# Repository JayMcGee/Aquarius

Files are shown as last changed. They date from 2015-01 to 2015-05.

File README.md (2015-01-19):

# Aquarius

The aquarius water quality evaluation station will be a programmable autonomous terminal. It will have acces to cellular network to transmit data to CloudIA, a scientific database and data visualisation interface.

The terminal evaluates water quality by acquiring acidity level (pH), water conductivity (µS/cm), dissolved oxygen (mg/L) and temperature(℃).  

-------------------------------------------------------------------------------------------------------------------------

La station d’évaluation de la qualité de l’eau Aquarius sera une borne autonome programmable. Elle aura la capacité de communiquer par réseau cellulaire ses données au logiciel CloudIA, une interface de visualisation de données scientifiques .

La borne permettra d’évaluer la qualité de l’eau en recueillant des mesures d’acidité (pH), de conductivité (µS/cm), de la concentration d’oxygène dissous (mg/L) et de la température (℃).

-------------------------------------------------------------------------------------------------------------------------

Aquarius is a Beaglebone Black with pH, dissolved oxygen, and conductivity sensors built by Atlas Scientific and a water temperature sensor by Dallas Semiconductor.

Each sensor has its own driver to calibrate or read a value. Those drivers are executed by an interface hosted on the apache server (/var/www) with a real-time interface written in Html connected to the server with Node.Js.

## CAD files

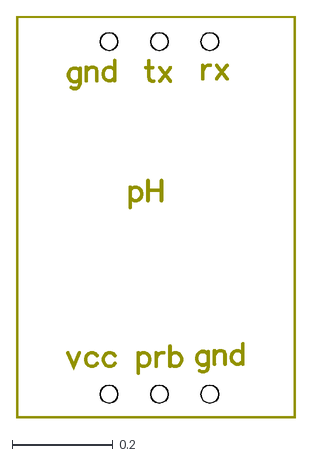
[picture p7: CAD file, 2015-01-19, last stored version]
brd/ph-layout.dxf
0.555 x 0.798

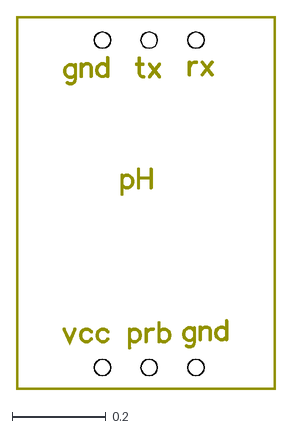
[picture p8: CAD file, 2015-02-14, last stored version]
brd_Jay_Alim/ph-layout.dxf
0.555 x 0.798

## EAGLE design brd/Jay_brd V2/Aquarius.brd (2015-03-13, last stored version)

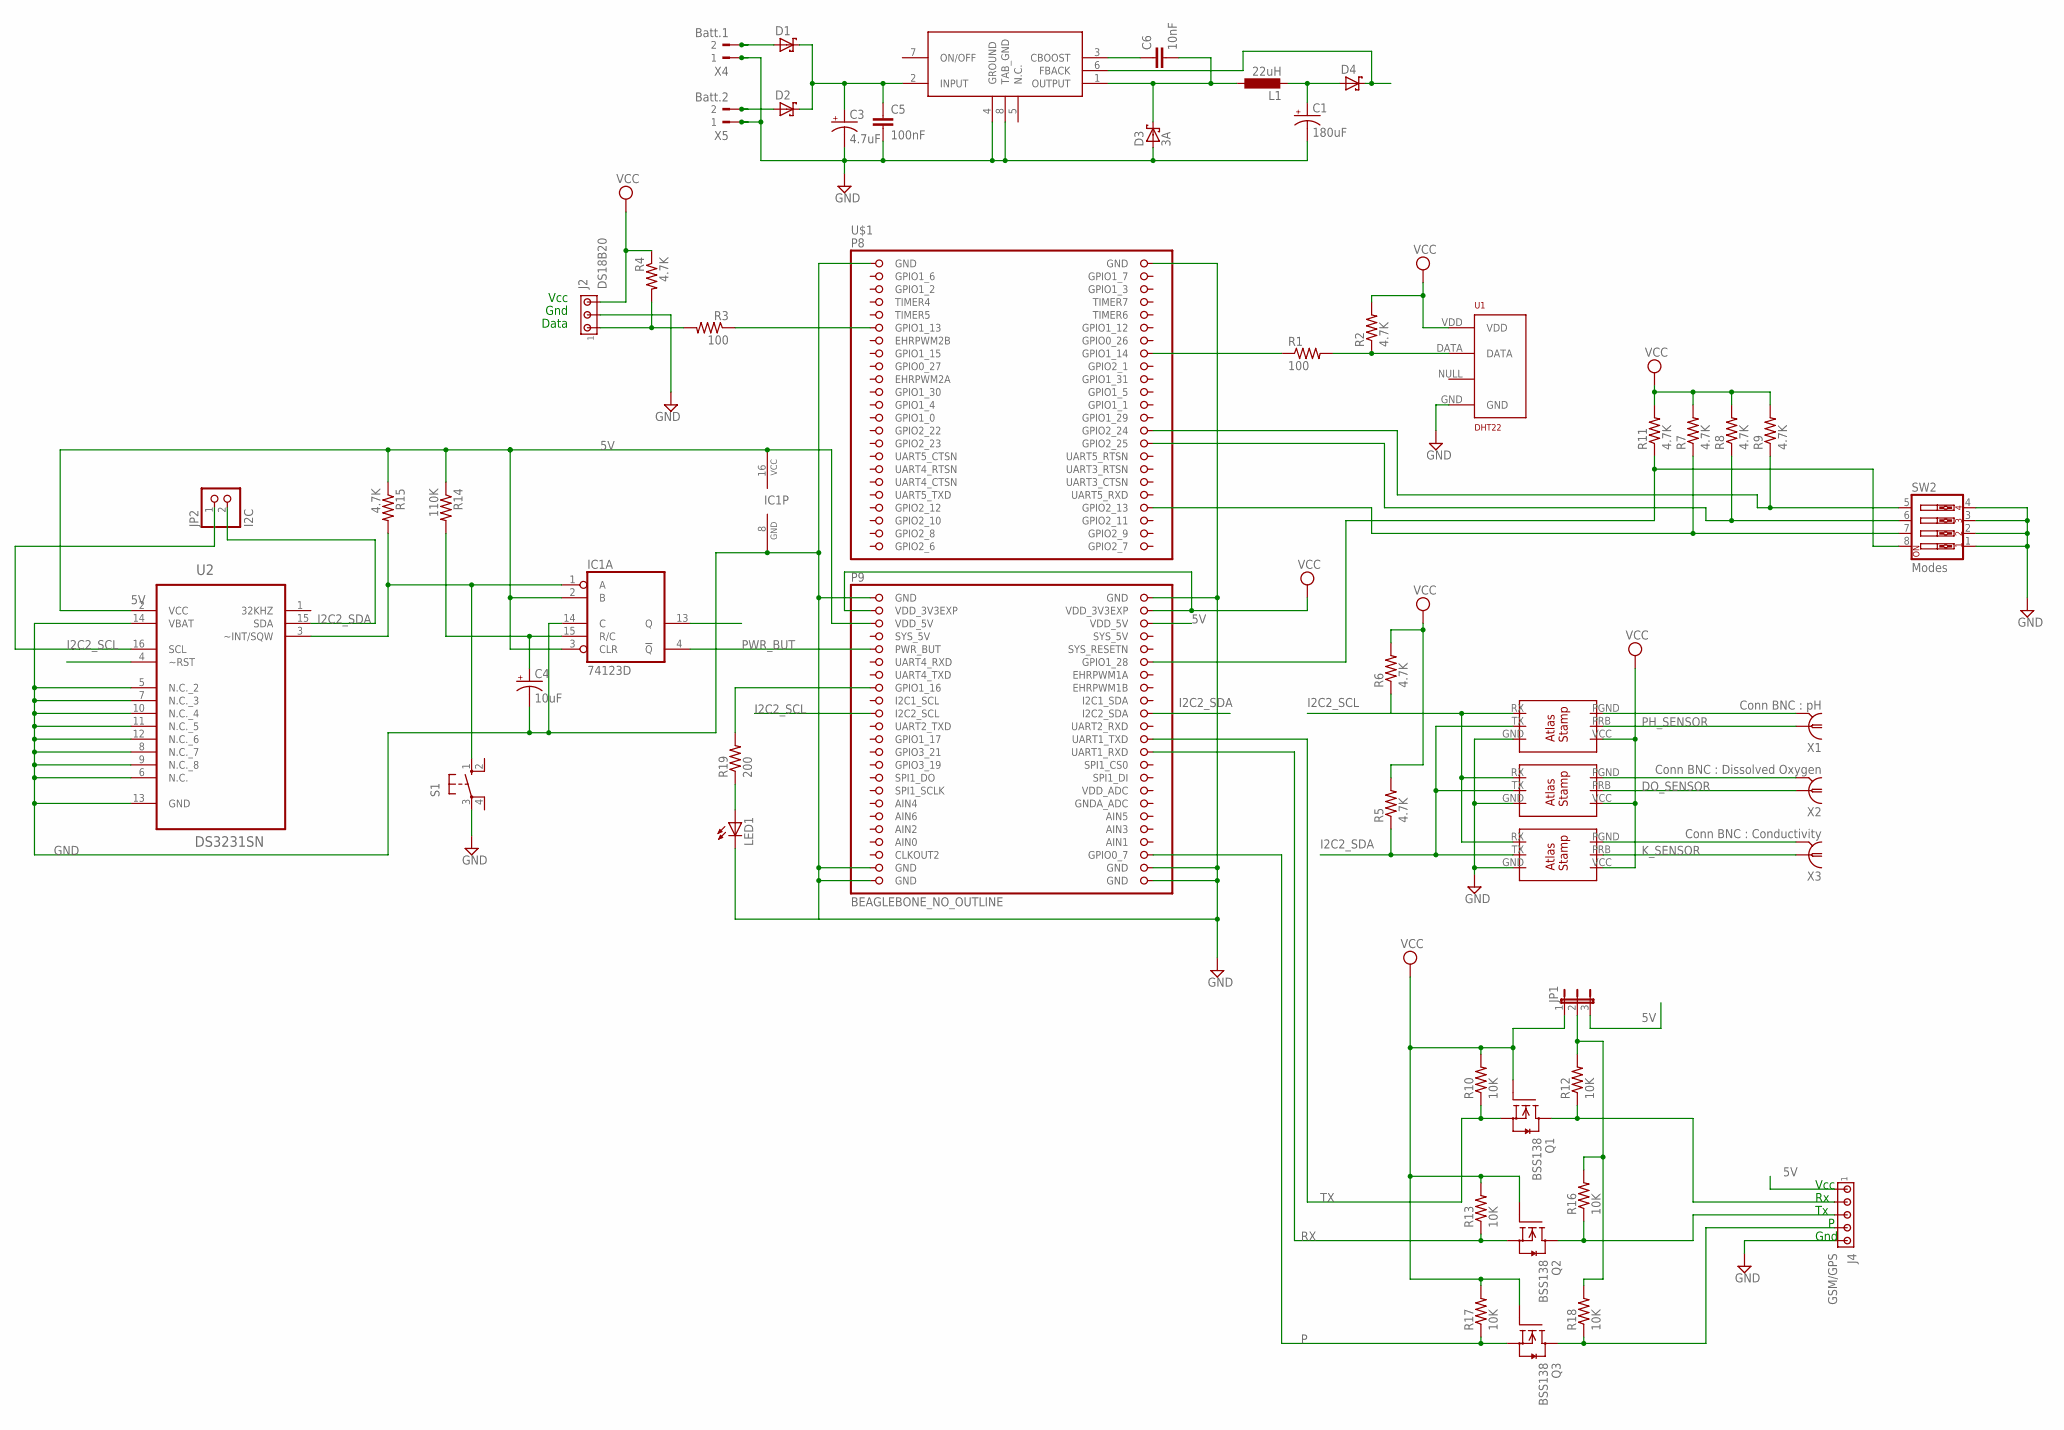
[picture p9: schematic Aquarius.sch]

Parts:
C1: 180uF; PANASONIC_D
C3: 4.7uF; PANASONIC_B
C4: 10uF; PANASONIC_B
C5: 100nF; C0805
C6: 10nF; C0805
D1, D2, D4: SCHOTTKY-DIODEDO201T15; DO201T15
D3: 3A; DO201T15
IC1: 74123D; SO16
J2: DS18B20; 10X03MTA
J4: GSM/GPS; 10X05MTA
JP1: JP2E; JP2
JP2: I2C; 1X02
L1: 22uH; EPCOS-10X10
LED1: LEDCHIP-LED0805; CHIP-LED0805
LM2678: LM2678KTW0007B; TO-PMOD7
Q1, Q2, Q3: BSS138; SOT23
R1, R3: 100; R0805
R2, R4, R5, R6, R7, R8, R9, R11, R15: 4.7K; R0805
R10, R12, R13, R16, R17, R18: 10K; R0805
R14: 110K; R0805
R19: 200; R0805
S1: 10-XX; B3F-10XX
SW2: Modes; EDG-04
U1: DHT22; AM2302
U2: DS3231SN; SOIC127P1032X265-16N
U$1: BEAGLEBONE_NO_OUTLINE; BEAGLEBONE_SHIELD_NO_OUTLINE
U$2, U$3, U$4: ATLAS_STAMP
X1: Conn BNC : pH; AMP_227161
X2: Conn BNC : Dissolved Oxygen; AMP_227161
X3: Conn BNC : Conductivity; AMP_227161
X4: Batt.1; 180G-2
X5: Batt.2; 180G-2

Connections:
5V: D4.C, IC1.2 (B), IC1.3 (CLR), IC1.16 (VCC), J4.1, JP1.3, LM2678.6 (FBACK), R14.1, R15.1, U2.2 (VCC), U$1.51 (VDD_5V), U$1.52 (VDD_5V)
AIN0: U$1.85 (AIN0)
DO_SENSOR: U$3.PRB, X2.1
GND: C1.-, C3.-, C4.-, C5.2, D3.A, IC1.8 (GND), IC1.14 (C), J2.2, J4.5, LED1.C, LM2678.4 (GROUND), LM2678.8 (TAB_GND), S1.3, SW2.1, SW2.2, SW2.3, SW2.4, U1.GND, U2.5 (N.C._2), U2.6 (N.C.), U2.7 (N.C._3), U2.8 (N.C._7), U2.9 (N.C._8), U2.10 (N.C._4), U2.11 (N.C._5), U2.12 (N.C._6), U2.13 (GND), U2.14 (VBAT), U$1.1 (GND), U$1.2 (GND), U$1.47 (GND), U$1.48 (GND), U$1.89 (GND), U$1.90 (GND), U$1.91 (GND), U$1.92 (GND), U$2.GND, U$3.GND, U$4.GND, X4.1, X5.1
I2C2_SCL: JP2.1, R6.1, U2.16 (SCL), U$1.65 (I2C2_SCL), U$2.RX, U$3.RX, U$4.RX
I2C2_SDA: JP2.2, R5.1, U2.15 (SDA), U$2.TX, U$3.TX, U$4.TX
INT: IC1.1 (A), R15.2, S1.1 (S), U2.3 (~INT/SQW)
K_SENSOR: U$4.PRB, X3.1
unnamed: J4.4, Q3.3 (D), R18.1
unnamed: D1.A, X4.2
unnamed: R1.2, R2.1, U1.DATA
unnamed: R3.1, U$1.11 (GPIO1_13)
unnamed: J2.1, R3.2, R4.2
unnamed: R1.1, U$1.16 (GPIO1_14)
unnamed: R7.1, SW2.7, U$1.40 (GPIO2_13)
unnamed: D2.A, X5.2
unnamed: C6.1, LM2678.3 (CBOOST)
unnamed: C3.+, C5.1, D1.C, D2.C, LM2678.2 (INPUT)
unnamed: U$2.PGND, X1.2
unnamed: C6.2, D3.C, L1.P$1 (1), LM2678.1 (OUTPUT)
unnamed: U$4.PGND, X3.2
unnamed: U$3.PGND, X2.2
unnamed: C1.+, D4.A, L1.P$2 (2)
unnamed: C4.+, IC1.15 (R/C), R14.2
unnamed: R11.1, SW2.8, U$1.58 (GPIO1_28)
unnamed: R8.1, SW2.6, U$1.30 (GPIO2_25)
unnamed: R9.1, SW2.5, U$1.28 (GPIO2_24)
unnamed: J4.3, Q2.3 (D), R16.1
unnamed: J4.2, Q1.3 (D), R12.1
unnamed: JP1.2, R12.2, R16.2, R18.2
unnamed: LED1.A, R19.1
unnamed: R19.2, U$1.61 (GPIO1_16)
P: Q3.2 (S), R17.1, U$1.88 (GPIO0_7)
PH_SENSOR: U$2.PRB, X1.1
PWR_BUT: IC1.4 (!Q), U$1.55 (PWR_BUT)
RX: Q2.2 (S), R13.1, U$1.72 (UART1_RXD)
SYS_5V: U$1.53 (SYS_5V)
TX: Q1.2 (S), R10.1, U$1.70 (UART1_TXD)
VCC: J2.3, JP1.1, Q1.1 (G), Q2.1 (G), Q3.1 (G), R2.2, R4.1, R5.2, R6.2, R7.2, R8.2, R9.2, R10.2, R11.2, R13.2, R17.2, U1.VDD, U$1.49 (VDD_3V3EXP), U$1.50 (VDD_3V3EXP), U$2.VCC, U$3.VCC, U$4.VCC

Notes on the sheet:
Vcc
Gnd
Data

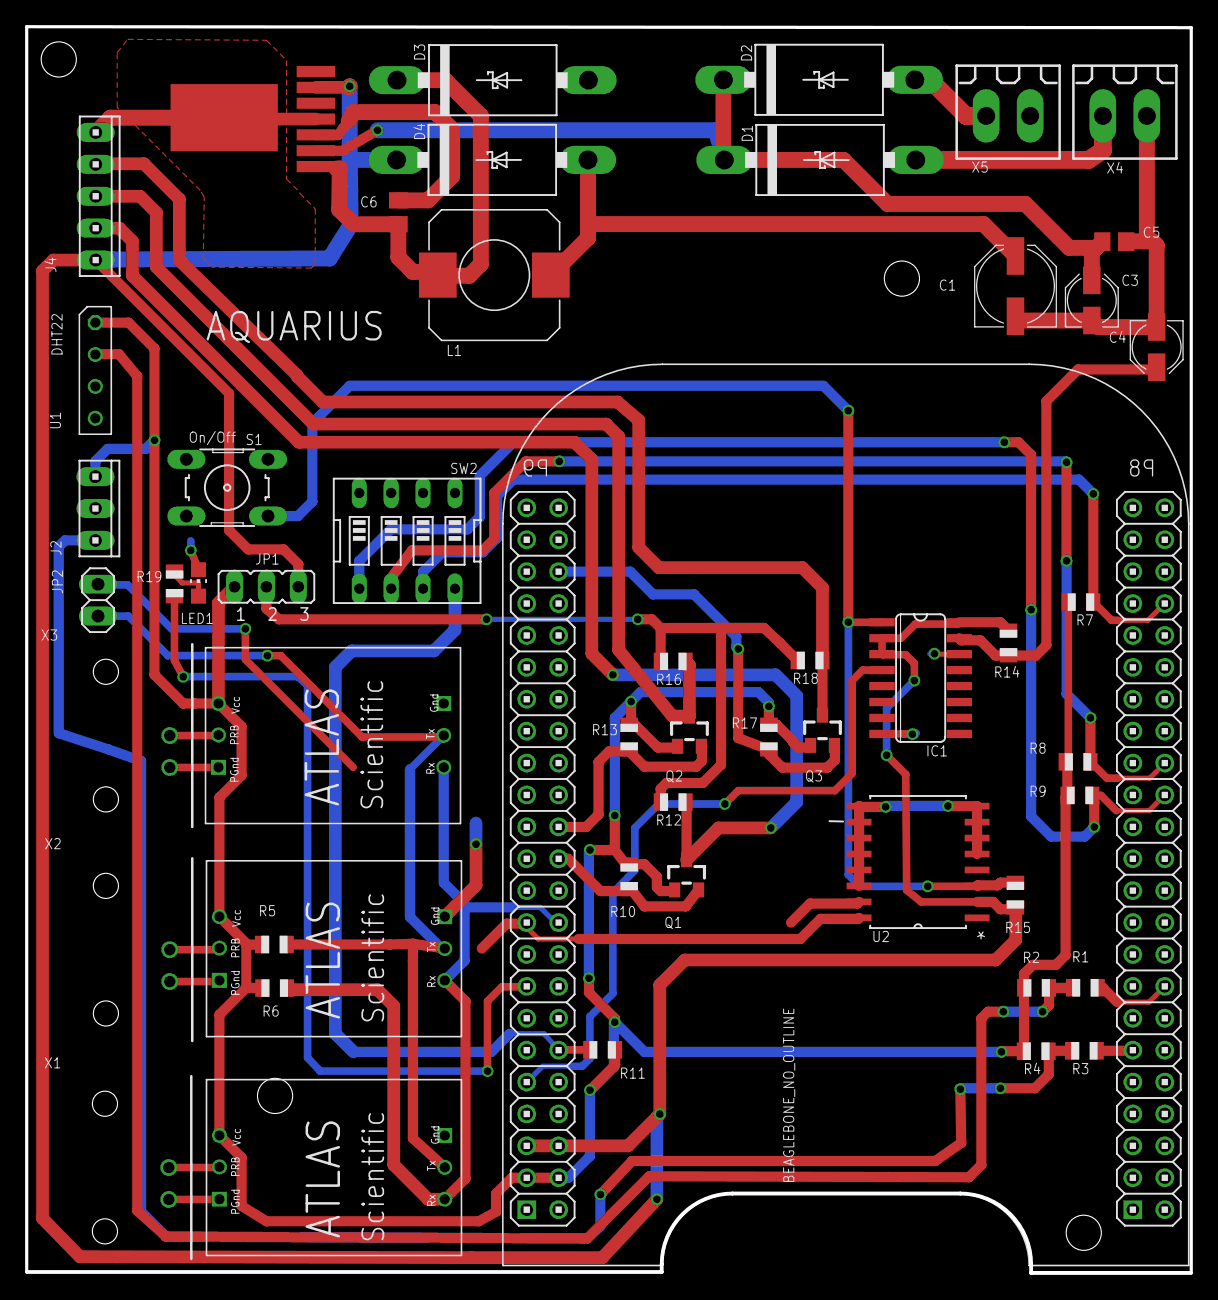
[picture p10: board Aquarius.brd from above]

Board: 2 copper layers, 92.7 x 99.2 mm, 53 parts (1 on the bottom side), 37 nets.

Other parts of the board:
DRILEGEND: DRILEGEND

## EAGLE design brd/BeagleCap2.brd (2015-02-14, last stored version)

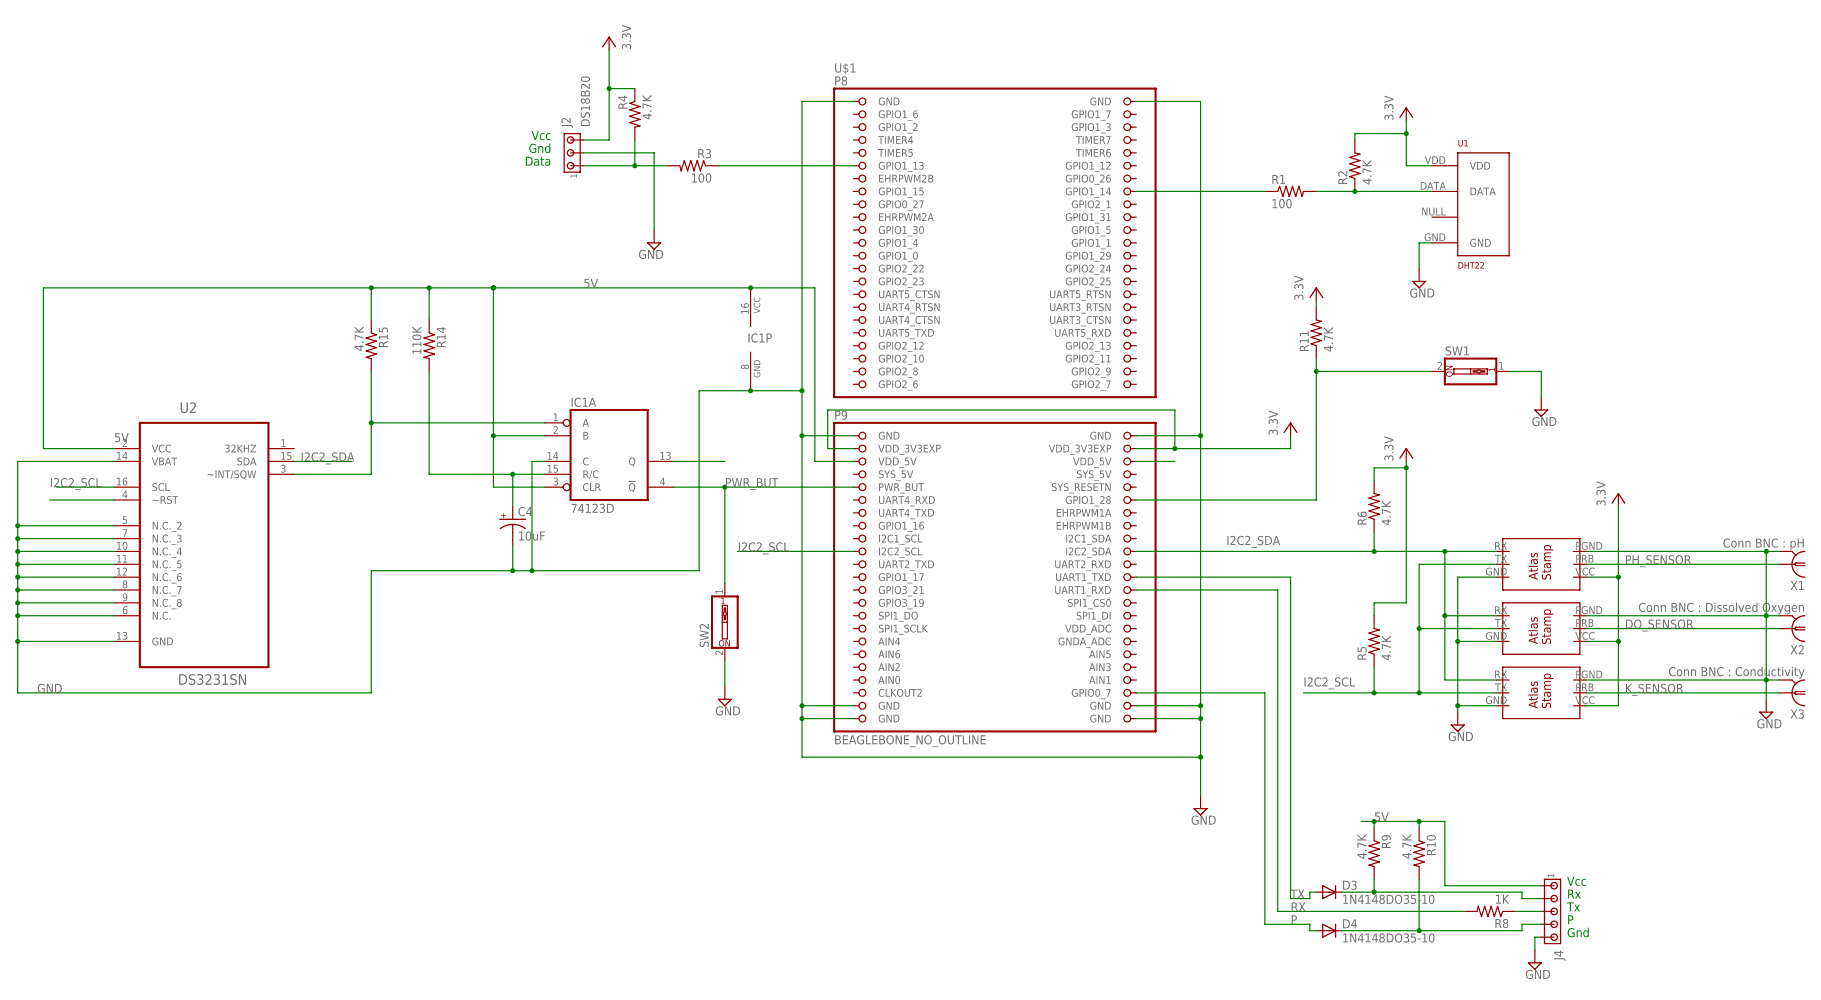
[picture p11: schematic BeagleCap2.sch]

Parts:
C4: 10uF; E2-5
D3, D4: 1N4148DO35-10; DO35-10
IC1: 74123D; SO16
J2: DS18B20; 10X03MTA
J4: MTA05-100; 10X05MTA
R1, R3: 100; R0805
R2, R4, R5, R6, R9, R10, R11, R15: 4.7K; R0805
R8: 1K; R0805
R14: 110K; R0805
SW1, SW2: SW_DIP-1; EDG-01
U1: DHT22; AM2302
U2: DS3231SN; SOIC127P1032X265-16N
U$1: BEAGLEBONE_NO_OUTLINE; BEAGLEBONE_SHIELD_NO_OUTLINE
U$2, U$3, U$4: ATLAS_STAMP
X1: Conn BNC : pH; AMP_227161
X2: Conn BNC : Dissolved Oxygen; AMP_227161
X3: Conn BNC : Conductivity; AMP_227161

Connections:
3.3V: J2.3, R2.2, R4.1, R5.2, R6.2, U1.VDD, U$1.49 (VDD_3V3EXP), U$1.50 (VDD_3V3EXP), U$2.VCC, U$3.VCC, U$4.VCC
5V: IC1.2 (B), IC1.3 (CLR), IC1.16 (VCC), J4.1, R9.1, R10.1, R14.1, R15.1, U2.2 (VCC), U$1.51 (VDD_5V)
AIN0: U$1.85 (AIN0)
DO_SENSOR: U$3.PRB, X2.1
GND: C4.-, IC1.8 (GND), IC1.14 (C), J2.2, J4.5, SW1.1, SW2.2, U1.GND, U2.5 (N.C._2), U2.6 (N.C.), U2.7 (N.C._3), U2.8 (N.C._7), U2.9 (N.C._8), U2.10 (N.C._4), U2.11 (N.C._5), U2.12 (N.C._6), U2.13 (GND), U2.14 (VBAT), U$1.1 (GND), U$1.2 (GND), U$1.47 (GND), U$1.48 (GND), U$1.89 (GND), U$1.90 (GND), U$1.91 (GND), U$1.92 (GND), U$2.GND, U$2.PGND, U$3.GND, U$3.PGND, U$4.GND, U$4.PGND, X1.2, X2.2, X3.2
I2C2_SCL: R5.1, U2.16 (SCL), U$1.65 (I2C2_SCL), U$2.TX, U$3.TX, U$4.TX
I2C2_SDA: R6.1, U2.15 (SDA), U$1.66 (I2C2_SDA), U$2.RX, U$3.RX, U$4.RX
INT: IC1.1 (A), R15.2, U2.3 (~INT/SQW)
K_SENSOR: U$4.PRB, X3.1
unnamed: R1.2, R2.1, U1.DATA
unnamed: R3.1, U$1.11 (GPIO1_13)
unnamed: J2.1, R3.2, R4.2
unnamed: R1.1, U$1.16 (GPIO1_14)
unnamed: R11.1, SW1.2, U$1.58 (GPIO1_28)
unnamed: D3.C, J4.2, R9.2
unnamed: J4.3, R8.1
unnamed: D4.C, J4.4, R10.2
unnamed: C4.+, IC1.15 (R/C), R14.2
P: D4.A, U$1.88 (GPIO0_7)
PH_SENSOR: U$2.PRB, X1.1
PWR_BUT: IC1.4 (!Q), SW2.1, U$1.55 (PWR_BUT)
RX: R8.2, U$1.72 (UART1_RXD)
SYS_5V: U$1.53 (SYS_5V)
TX: D3.A, U$1.70 (UART1_TXD)
VCC: R11.2

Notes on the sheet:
Vcc
Gnd
Data

Board: 2 copper layers, 29 parts (1 on the bottom side), 22 nets, no tracks yet.

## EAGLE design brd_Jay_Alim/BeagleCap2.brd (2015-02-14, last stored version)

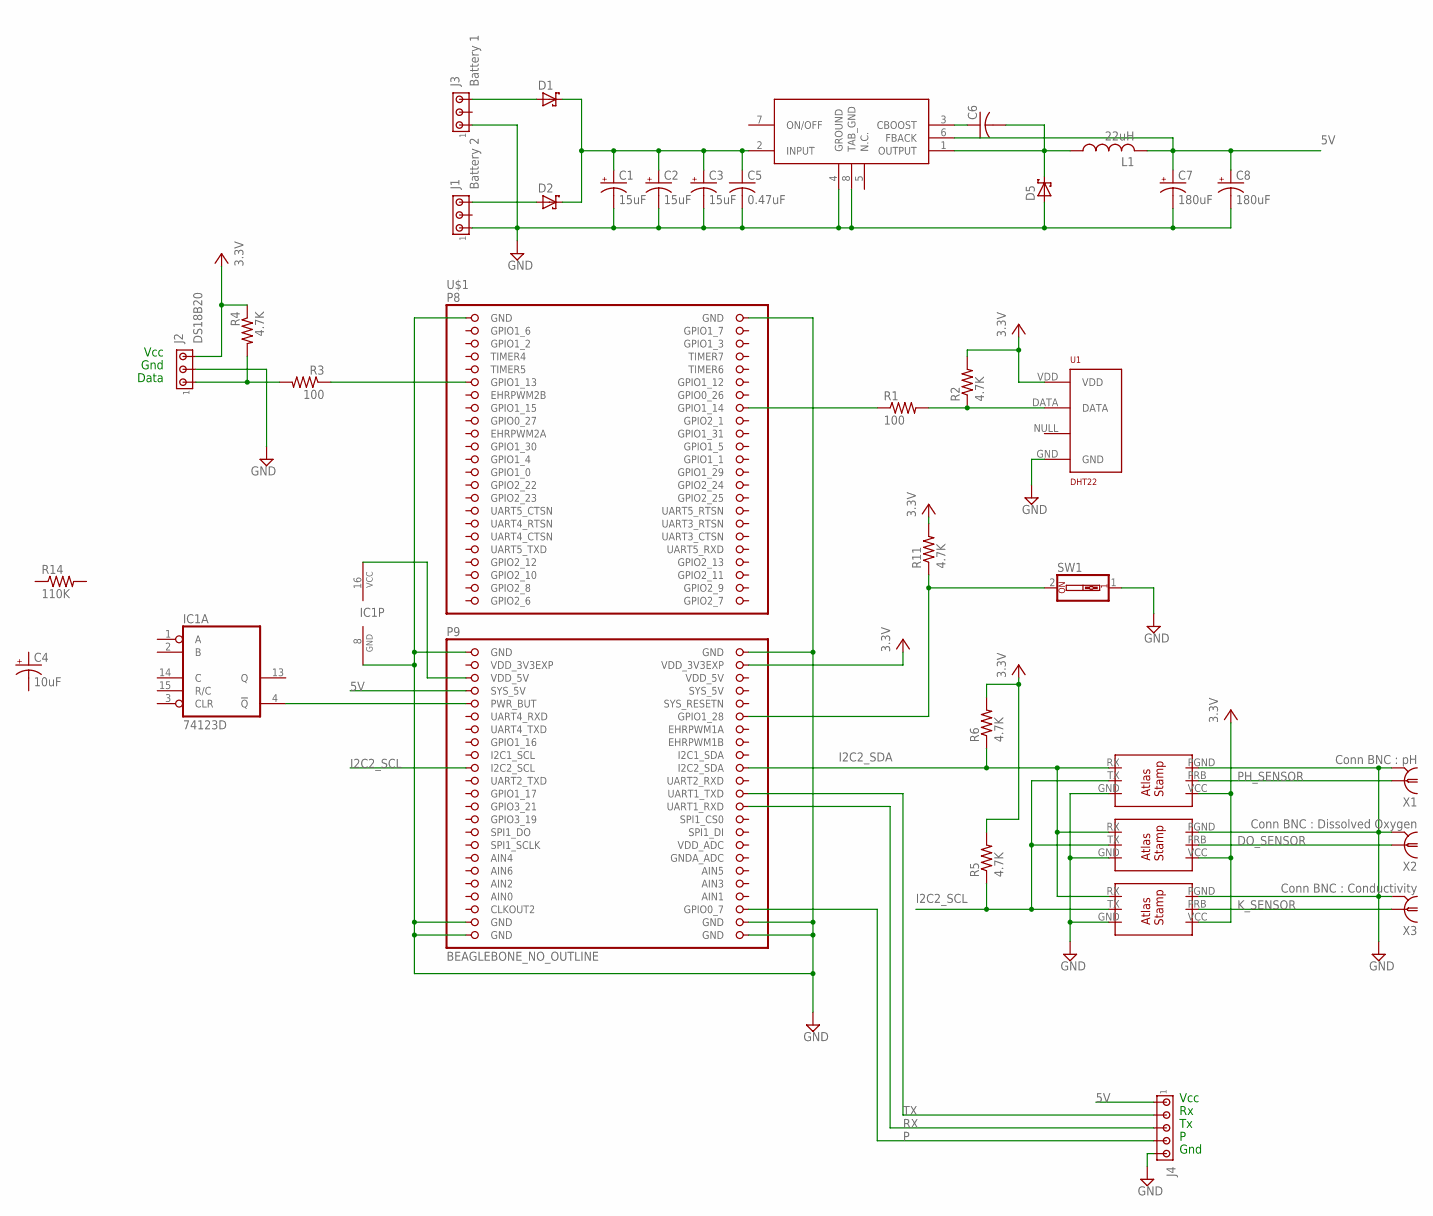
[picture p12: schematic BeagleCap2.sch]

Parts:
C1, C2, C3: 15uF; 153CLV-0405
C4: 10uF; E2-5
C5: 0.47uF; C025-025X050
C6: C-US025-025X050; C025-025X050
C7, C8: 180uF; E2,5-7
D1, D2: SCHOTTKY-DIODECB417-15; CB417-15
D5: SCHOTTKY-DIODEDO41-7; DO41-7
IC1: 74123D; SO16
J1: Battery 2; 10X03MTA
J2: DS18B20; 10X03MTA
J3: Battery 1; 10X03MTA
J4: MTA05-100; 10X05MTA
L1: 22uH; 0204/7
R1, R3: 100; R0805
R2, R4, R5, R6, R11: 4.7K; R0805
R14: 110K; R0805
SW1: SW_DIP-1; EDG-01
U1: DHT22; AM2302
U$1: BEAGLEBONE_NO_OUTLINE; BEAGLEBONE_SHIELD_NO_OUTLINE
U$2, U$3, U$4: ATLAS_STAMP
U$7: LM2678KTW0007B; TO-PMOD7
X1: Conn BNC : pH; AMP_227161
X2: Conn BNC : Dissolved Oxygen; AMP_227161
X3: Conn BNC : Conductivity; AMP_227161

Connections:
3.3V: J2.3, R2.2, R4.1, R5.2, R6.2, U1.VDD, U$1.50 (VDD_3V3EXP), U$2.VCC, U$3.VCC, U$4.VCC
5V: C7.+, C8.+, IC1.16 (VCC), J4.1, L1.2, U$1.51 (VDD_5V), U$1.53 (SYS_5V), U$7.6 (FBACK)
AIN0: U$1.85 (AIN0)
DO_SENSOR: U$3.PRB, X2.1
GND: C1.-, C2.-, C3.-, C5.2, C7.-, C8.-, D5.A, IC1.8 (GND), J1.1, J2.2, J3.1, J4.5, SW1.1, U1.GND, U$1.1 (GND), U$1.2 (GND), U$1.47 (GND), U$1.48 (GND), U$1.89 (GND), U$1.90 (GND), U$1.91 (GND), U$1.92 (GND), U$2.GND, U$2.PGND, U$3.GND, U$3.PGND, U$4.GND, U$4.PGND, U$7.4 (GROUND), U$7.8 (TAB_GND), X1.2, X2.2, X3.2
I2C2_SCL: R5.1, U$1.65 (I2C2_SCL), U$2.TX, U$3.TX, U$4.TX
I2C2_SDA: R6.1, U$1.66 (I2C2_SDA), U$2.RX, U$3.RX, U$4.RX
K_SENSOR: U$4.PRB, X3.1
unnamed: D2.A, J1.3
unnamed: D1.A, J3.3
unnamed: R1.2, R2.1, U1.DATA
unnamed: R3.1, U$1.11 (GPIO1_13)
unnamed: J2.1, R3.2, R4.2
unnamed: R1.1, U$1.16 (GPIO1_14)
unnamed: R11.1, SW1.2, U$1.58 (GPIO1_28)
unnamed: C1.+, C2.+, C3.+, C5.1, D1.C, D2.C, U$7.2 (INPUT)
unnamed: C6.1, U$7.3 (CBOOST)
unnamed: C6.2, D5.C, L1.1, U$7.1 (OUTPUT)
unnamed: IC1.4 (!Q), U$1.55 (PWR_BUT)
P: J4.4, U$1.88 (GPIO0_7)
PH_SENSOR: U$2.PRB, X1.1
RX: J4.3, U$1.72 (UART1_RXD)
TX: J4.2, U$1.70 (UART1_TXD)
VCC: R11.2
VDD_3V3EXP: U$1.49 (VDD_3V3EXP)
VDD_5V: U$1.52 (VDD_5V)

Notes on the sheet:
Vcc
Gnd
Data

Board: 2 copper layers, 35 parts (1 on the bottom side), 22 nets, no tracks yet.

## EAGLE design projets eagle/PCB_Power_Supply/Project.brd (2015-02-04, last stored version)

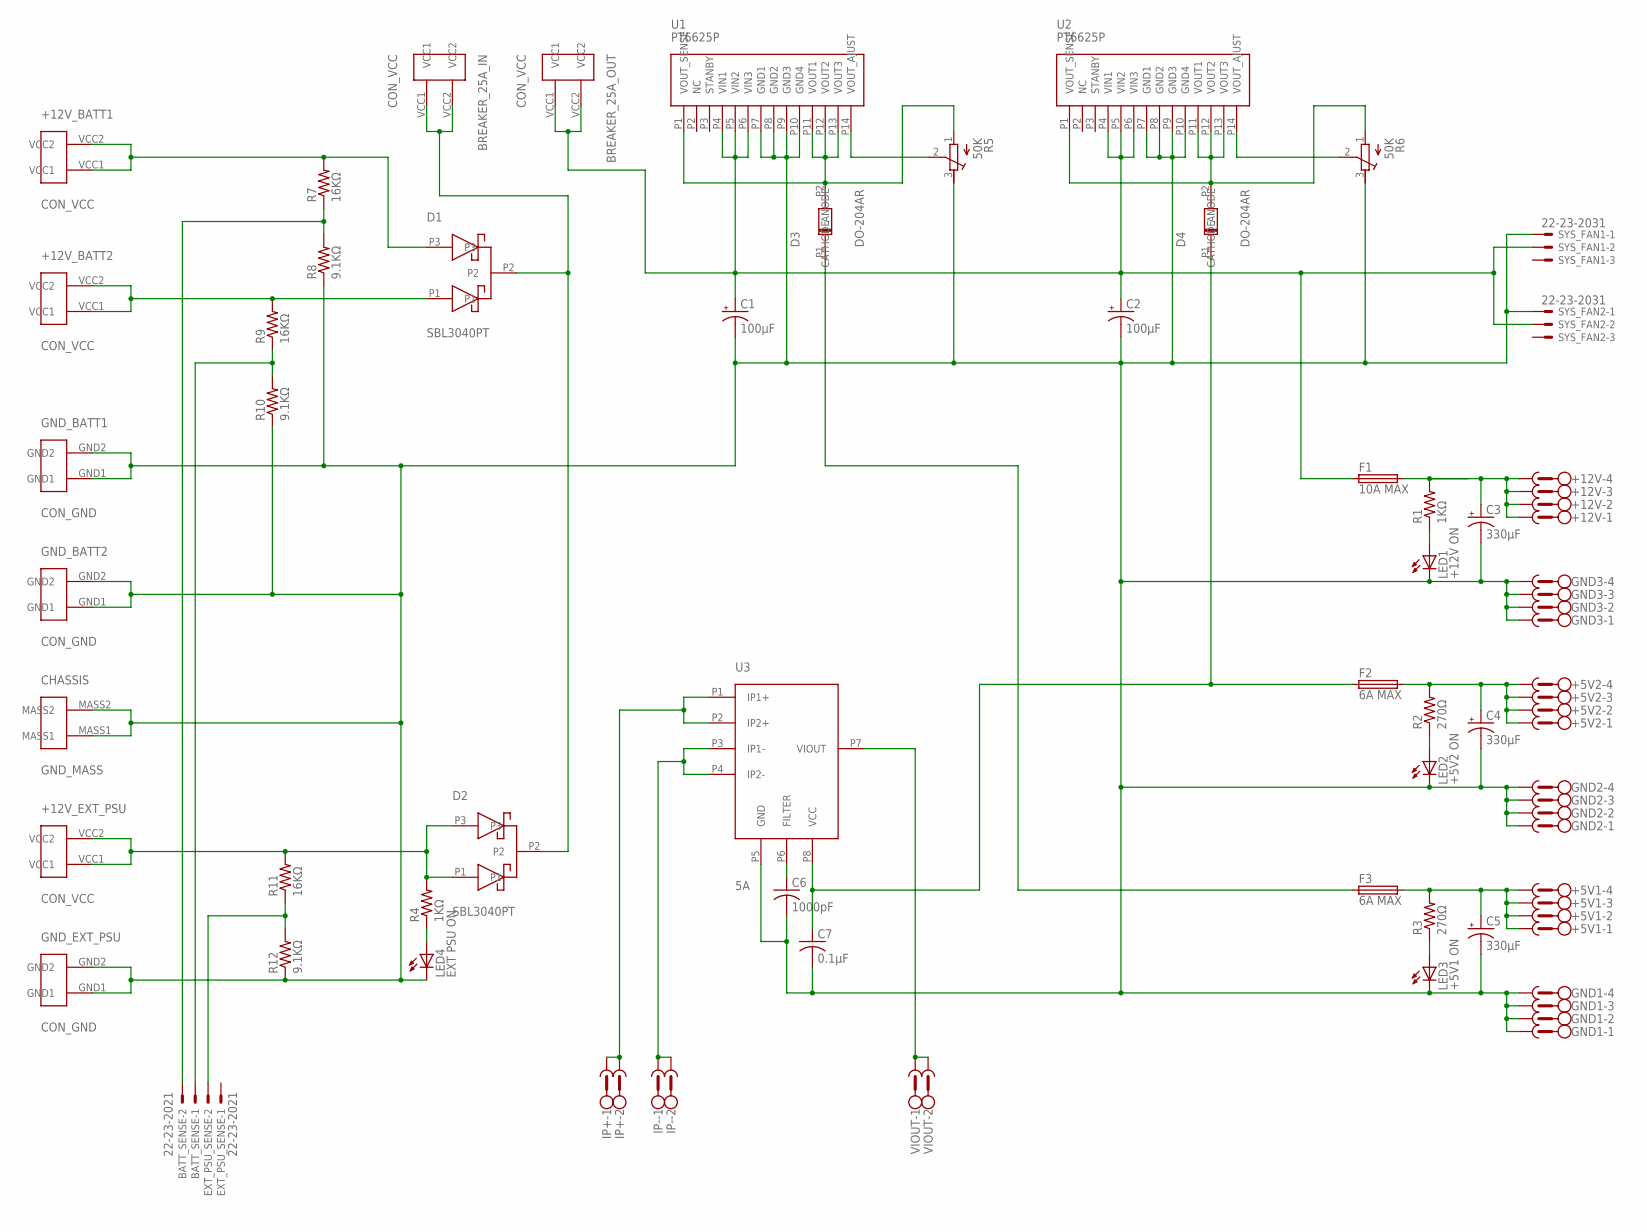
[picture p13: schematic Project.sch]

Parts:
+5V1, +5V2, +12V: MC1.5/4-G-3.81
+12V_BATT1, +12V_BATT2, +12V_EXT_PSU: CON_VCC
BATT_SENSE: 22-23-2021
BREAKER_25A_IN, BREAKER_25A_OUT: CON_VCC
C1, C2: 100µF; E2,5-6
C3, C4, C5: 330µF; E5-10,5
C6: 1000pF; C0805
C7: 0.1µF; C0805
CHASSIS: GND_MASS; CON_MASS
D1, D2: SBL3040PT
D3, D4: DO-204AR
EXT_PSU_SENSE: 22-23-2021
F1: 10A MAX; SH22,5
F2, F3: 6A MAX; SH22,5
GND1, GND2, GND3: MC1.5/4-G-3.81
GND_BATT1, GND_BATT2: CON_GND
GND_EXT_PSU: CON_GND
IP+: MC1.5/2-G-3.81
IP-: MC1.5/2-G-3.81
LED1: +12V ON; CHIP-LED0805
LED2: +5V2 ON; CHIP-LED0805
LED3: +5V1 ON; CHIP-LED0805
LED4: EXT PSU ON; CHIP-LED0805
R1, R4: 1KΩ; M0805
R2, R3: 270Ω; M0805
R5, R6: 50K; RTRIM3296Y
R7, R9, R11: 16KΩ; R0805
R8, R10, R12: 9.1KΩ; R0805
SYS_FAN1, SYS_FAN2: 22-23-2031
U1, U2: PT6625P
U3: 5A; ACS712
VIOUT: MC1.5/2-G-3.81

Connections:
GND: C1.-, C2.-, C3.-, C4.-, C5.-, C6.2, C7.2, CHASSIS.MASS1, CHASSIS.MASS2, GND1.1, GND1.2, GND1.3, GND1.4, GND2.1, GND2.2, GND2.3, GND2.4, GND3.1, GND3.2, GND3.3, GND3.4, GND_BATT1.GND1, GND_BATT1.GND2, GND_BATT2.GND1, GND_BATT2.GND2, GND_EXT_PSU.GND1, GND_EXT_PSU.GND2, LED1.C, LED2.C, LED3.C, LED4.C, R5.3 (A), R6.3 (A), R8.1, R10.1, R12.1, SYS_FAN1.1, SYS_FAN2.1, U1.P7 (GND1), U1.P8 (GND2), U1.P9 (GND3), U1.P10 (GND4), U2.P7 (GND1), U2.P8 (GND2), U2.P9 (GND3), U2.P10 (GND4), U3.P5 (GND)
unnamed: LED3.A, R3.1
unnamed: BATT_SENSE.2, R7.1, R8.2
unnamed: LED2.A, R2.1
unnamed: U3.P7 (VIOUT), VIOUT.1, VIOUT.2
unnamed: LED1.A, R1.1
unnamed: D4.P2 (CATHODE), R6.1 (E), U2.P1 (VOUT_SENSE), U2.P11 (VOUT1), U2.P12 (VOUT2), U2.P13 (VOUT3)
unnamed: +12V_BATT1.VCC1, +12V_BATT1.VCC2, D1.P3, R7.2
unnamed: +12V_BATT2.VCC1, +12V_BATT2.VCC2, D1.P1, R9.2
unnamed: +5V2.1, +5V2.2, +5V2.3, +5V2.4, C4.+, F2.2, R2.2
unnamed: BREAKER_25A_IN.VCC1, BREAKER_25A_IN.VCC2, D1.P2, D2.P2
unnamed: +12V.1, +12V.2, +12V.3, +12V.4, C3.+, F1.2, R1.2
unnamed: +12V_EXT_PSU.VCC1, +12V_EXT_PSU.VCC2, D2.P1, D2.P3, R4.2, R11.2
unnamed: +5V1.1, +5V1.2, +5V1.3, +5V1.4, C5.+, F3.2, R3.2
unnamed: LED4.A, R4.1
unnamed: IP-.1, IP-.2, U3.P3 (IP1-), U3.P4 (IP2-)
unnamed: R5.2 (S), U1.P14 (VOUT_AJUST)
unnamed: D3.P2 (CATHODE), R5.1 (E), U1.P1 (VOUT_SENSE), U1.P11 (VOUT1), U1.P12 (VOUT2), U1.P13 (VOUT3)
unnamed: R6.2 (S), U2.P14 (VOUT_AJUST)
unnamed: D3.P1 (ANODE), F3.1
unnamed: C6.1, U3.P6 (FILTER)
unnamed: BREAKER_25A_OUT.VCC1, BREAKER_25A_OUT.VCC2, C1.+, C2.+, F1.1, SYS_FAN1.2, SYS_FAN2.2, U1.P4 (VIN1), U1.P5 (VIN2), U1.P6 (VIN3), U2.P4 (VIN1), U2.P5 (VIN2), U2.P6 (VIN3)
unnamed: C7.1, D4.P1 (ANODE), F2.1, U3.P8 (VCC)
unnamed: IP+.1, IP+.2, U3.P1 (IP1+), U3.P2 (IP2+)
unnamed: BATT_SENSE.1, R9.1, R10.2
unnamed: EXT_PSU_SENSE.2, R11.1, R12.2

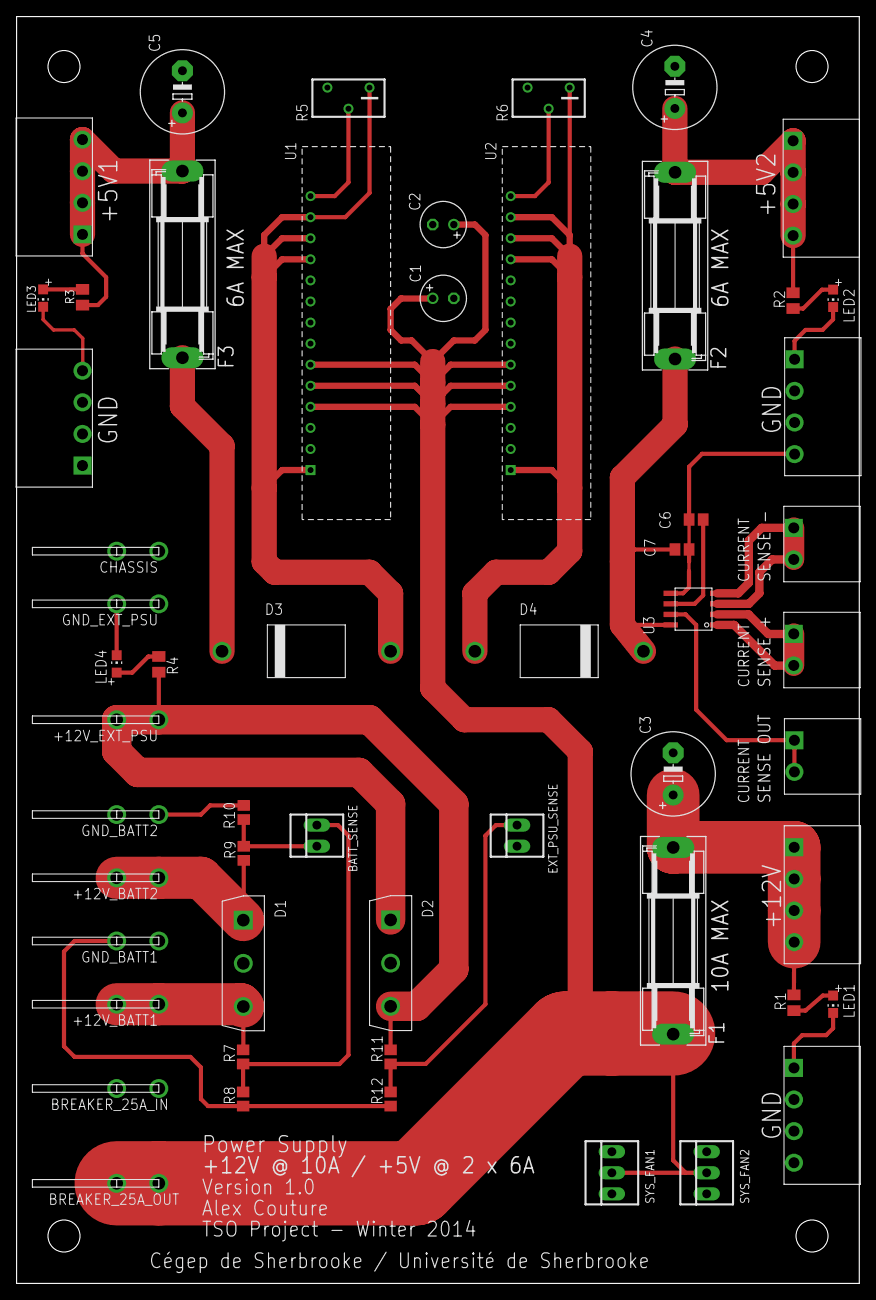
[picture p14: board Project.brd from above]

Board: 2 copper layers, 101.6 x 152.7 mm, 55 parts (0 on the bottom side), 26 nets.

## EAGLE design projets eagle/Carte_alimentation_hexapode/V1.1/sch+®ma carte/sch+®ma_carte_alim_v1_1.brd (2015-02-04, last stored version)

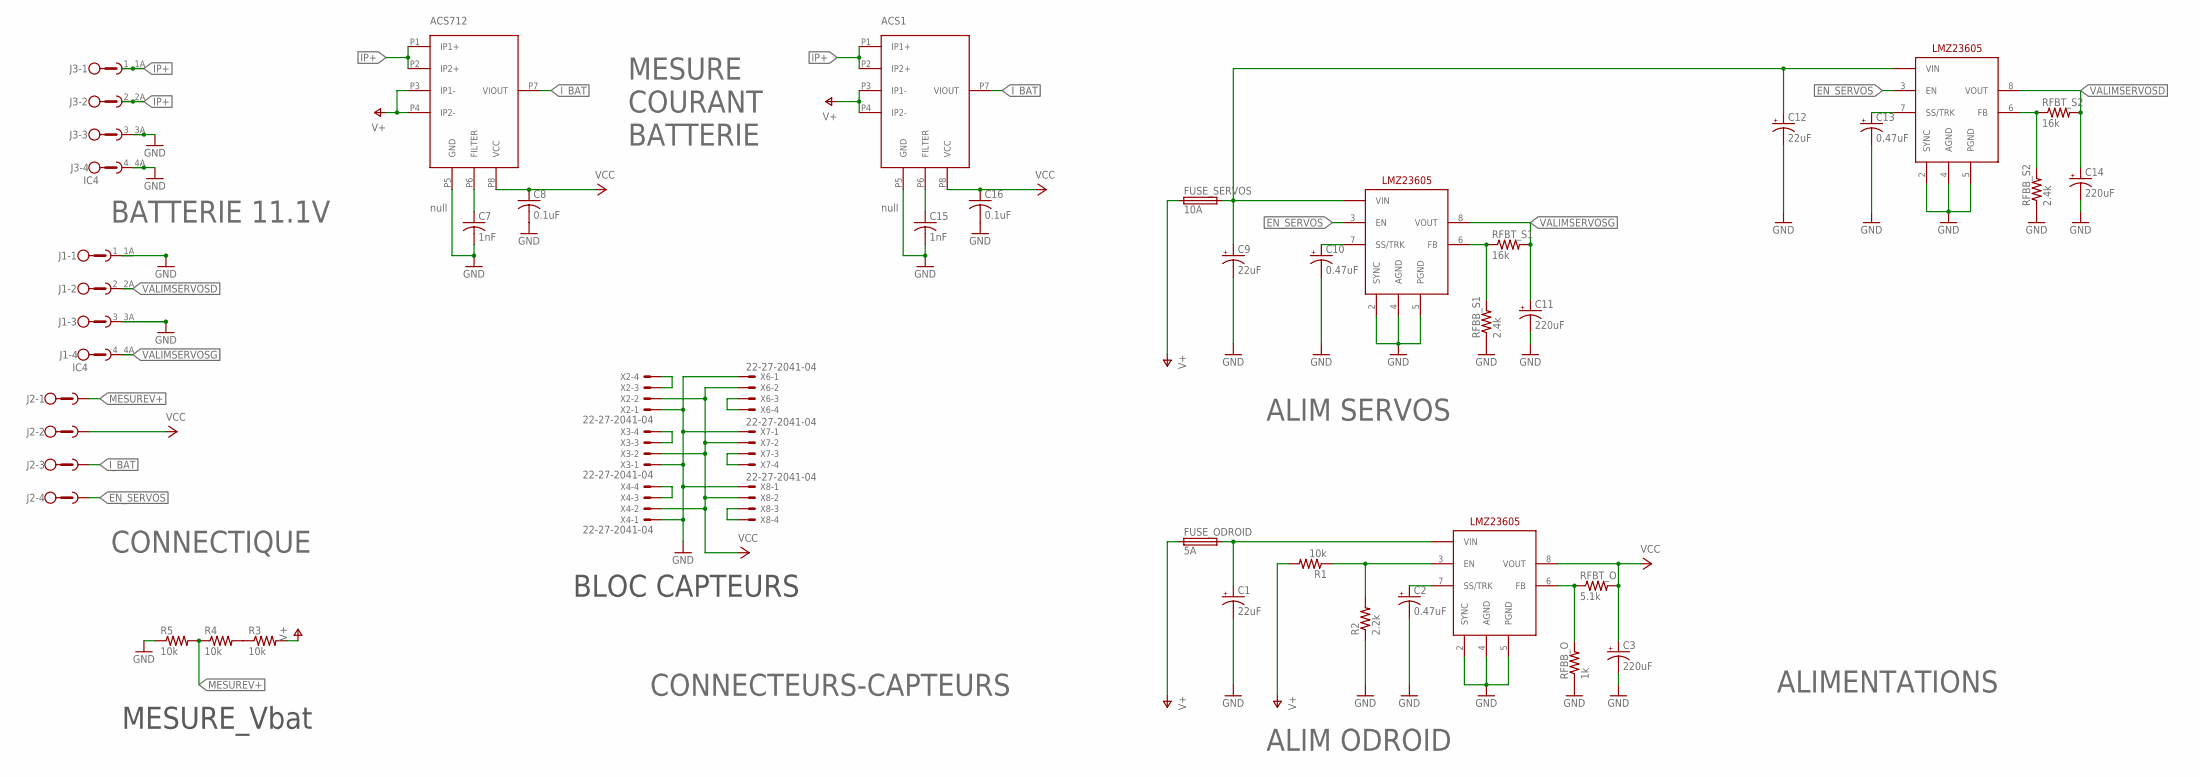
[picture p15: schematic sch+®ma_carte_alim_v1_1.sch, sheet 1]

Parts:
ACS1, ACS712: null; ACS712
ALIM_ODROID: LMZ23605
ALIM_SERVOS1, ALIM_SERVOS2: LMZ23605
C1, C9, C12: 22uF; E2,5-6
C2, C10, C13: 0.47uF; E2-5
C3, C11, C14: 220uF; E3,5-8
C7, C15: 1nF; C0805
C8, C16: 0.1uF; C0805
FUSE_ODROID: 5A; SH22,5
FUSE_SERVOS: 10A; SH22,5
J1, J3: IC4
J2: MC1.5/4-G-3.81
R1: 10k; R0805
R2: 2.2k; R0805
R3, R4, R5: 10k; M0805
RFBB_O: 1k; R0805
RFBB_S1, RFBB_S2: 2.4k; R0805
RFBT_O: 5.1k; R0805
RFBT_S1, RFBT_S2: 16k; R0805
X2, X3, X4, X6, X7, X8: 22-27-2041-04; 6410-04

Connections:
EN_SERVOS: ALIM_SERVOS1.3 (EN), ALIM_SERVOS2.3 (EN), J2.4
GND: ACS1.P5 (GND), ACS712.P5 (GND), ALIM_ODROID.2 (SYNC), ALIM_ODROID.4 (AGND), ALIM_ODROID.5 (PGND), ALIM_SERVOS1.2 (SYNC), ALIM_SERVOS1.4 (AGND), ALIM_SERVOS1.5 (PGND), ALIM_SERVOS2.2 (SYNC), ALIM_SERVOS2.4 (AGND), ALIM_SERVOS2.5 (PGND), C1.-, C2.-, C3.-, C7.2, C8.2, C9.-, C10.-, C11.-, C12.-, C13.-, C14.-, C15.2, C16.2, J1.1, J1.1A (2), J1.3 (1), J1.3A (2), J3.3 (1), J3.3A (2), J3.4 (1), J3.4A (2), R2.1, R5.1, RFBB_O.1, RFBB_S1.1, RFBB_S2.1, X2.1, X3.1, X4.1, X6.1, X7.1, X8.1
IP+: ACS1.P1 (IP1+), ACS1.P2 (IP2+), ACS712.P1 (IP1+), ACS712.P2 (IP2+), J3.1, J3.1A (2), J3.2 (1), J3.2A (2)
I_BAT: ACS1.P7 (VIOUT), ACS712.P7 (VIOUT), J2.3
MESUREV+: J2.1, R4.1, R5.2
unnamed: X6.3, X6.4
unnamed: ALIM_ODROID.7 (SS/TRK), C2.+
unnamed: ALIM_ODROID.6 (FB), RFBB_O.2, RFBT_O.1
unnamed: R3.1, R4.2
unnamed: ACS1.P6 (FILTER), C15.1
unnamed: X7.3, X7.4
unnamed: ALIM_ODROID.3 (EN), R1.1, R2.2
unnamed: X8.3, X8.4
unnamed: ACS712.P6 (FILTER), C7.1
unnamed: ALIM_SERVOS1.7 (SS/TRK), C10.+
unnamed: X2.3, X2.4
unnamed: X3.3, X3.4
unnamed: X4.3, X4.4
unnamed: ALIM_SERVOS1.6 (FB), RFBB_S1.2, RFBT_S1.1
unnamed: ALIM_SERVOS2.7 (SS/TRK), C13.+
unnamed: ALIM_SERVOS2.6 (FB), RFBB_S2.2, RFBT_S2.1
V+: ACS1.P3 (IP1-), ACS1.P4 (IP2-), ACS712.P3 (IP1-), ACS712.P4 (IP2-), FUSE_ODROID.1, FUSE_SERVOS.1, R1.2, R3.2
VALIMSERVOSD: ALIM_SERVOS2.8 (VOUT), C14.+, J1.2 (1), J1.2A (2), RFBT_S2.2
VALIMSERVOSG: ALIM_SERVOS1.8 (VOUT), C11.+, J1.4 (1), J1.4A (2), RFBT_S1.2
VCC: ACS1.P8 (VCC), ACS712.P8 (VCC), ALIM_ODROID.8 (VOUT), C3.+, C8.1, C16.1, J2.2, RFBT_O.2, X2.2, X3.2, X4.2, X6.2, X7.2, X8.2
VIN: ALIM_SERVOS1.1 (VIN), ALIM_SERVOS2.1 (VIN), C9.+, C12.+, FUSE_SERVOS.2
VINO: ALIM_ODROID.1 (VIN), C1.+, FUSE_ODROID.2

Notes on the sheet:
CONNECTIQUE
BATTERIE 11.1V
MESURE COURANT BATTERIE
MESURE_Vbat
BLOC CAPTEURS
ALIM ODROID
ALIM SERVOS
ALIMENTATIONS
CONNECTEURS-CAPTEURS

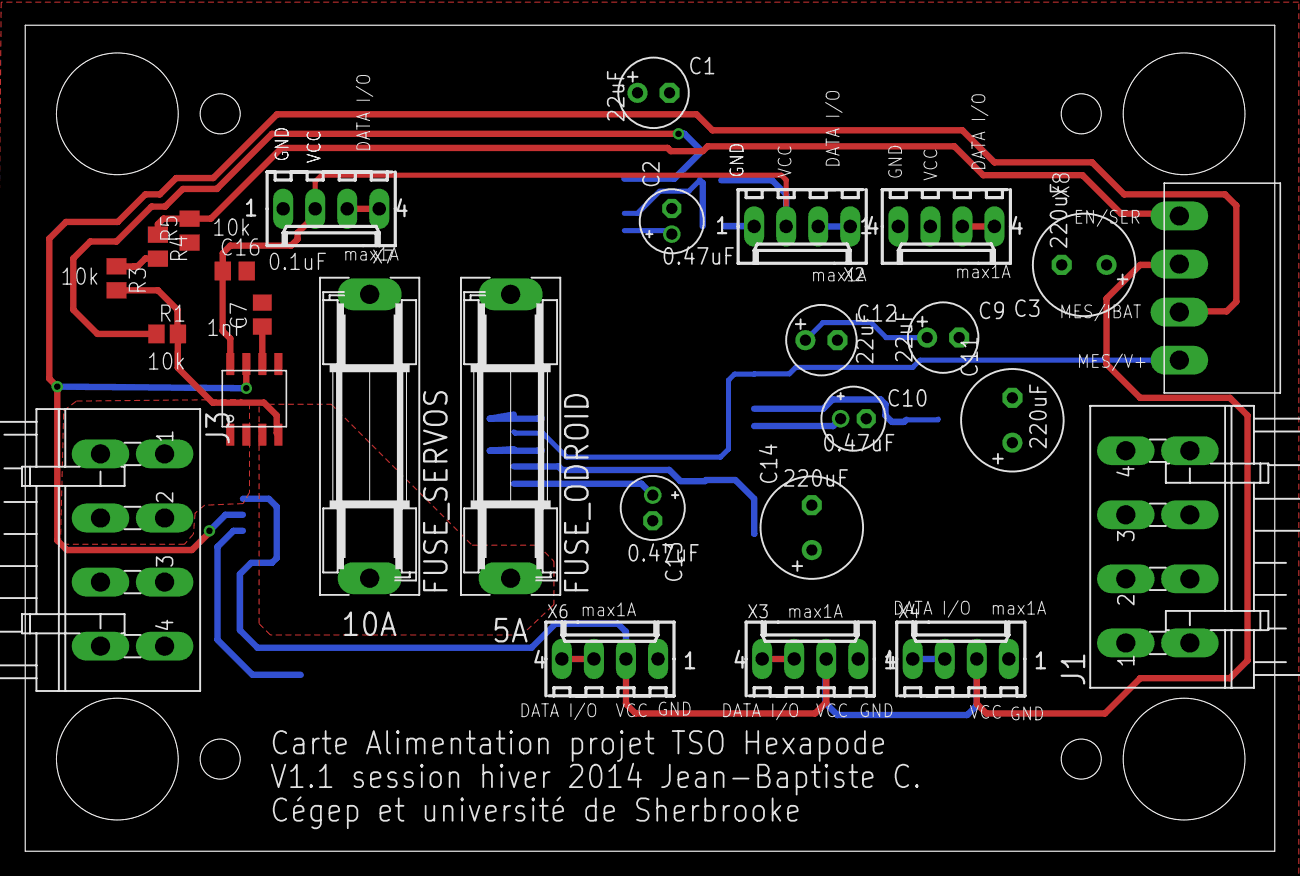
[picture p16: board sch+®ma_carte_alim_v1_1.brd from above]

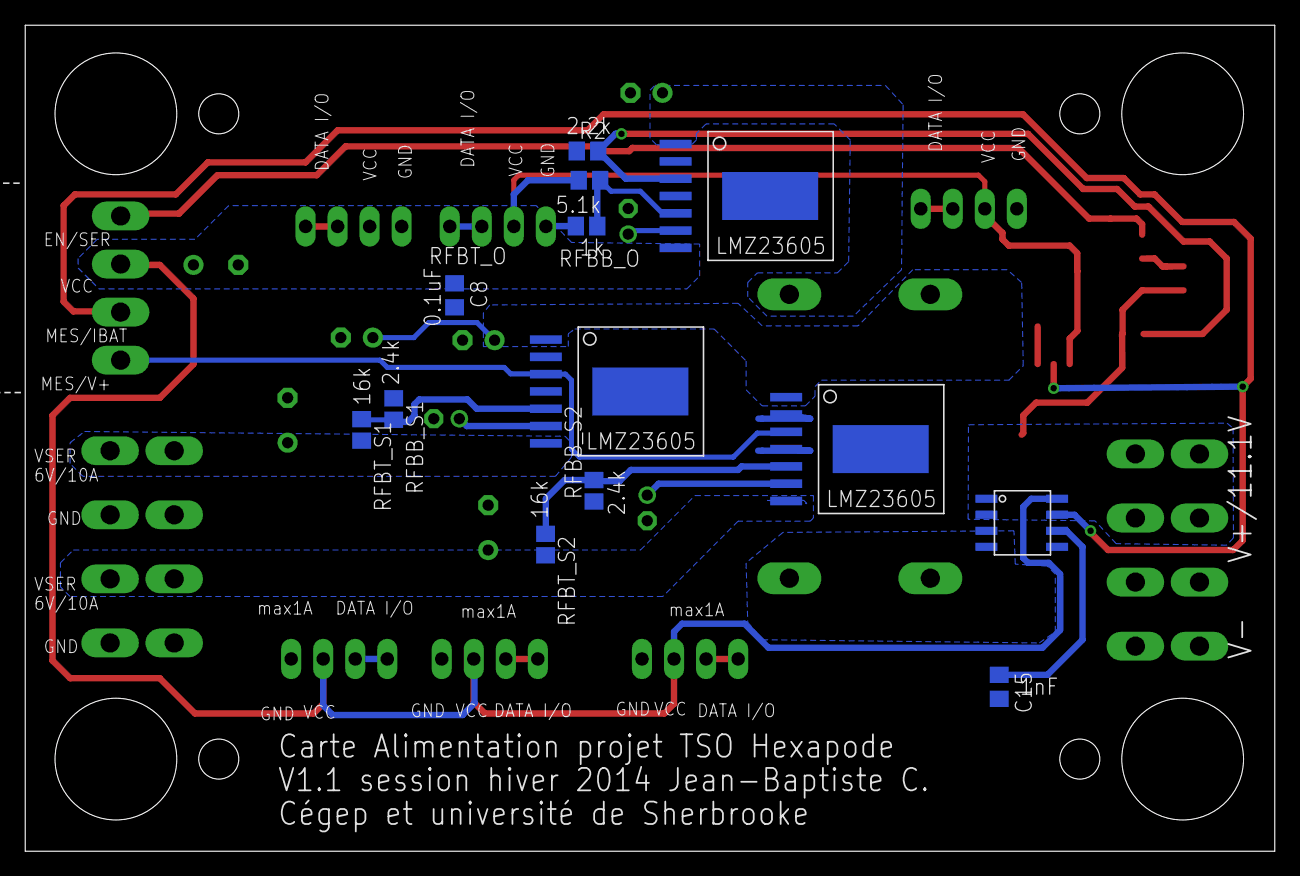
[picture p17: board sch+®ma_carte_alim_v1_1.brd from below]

Board: 2 copper layers, 99.1 x 65.5 mm, 40 parts (13 on the bottom side), 27 nets.

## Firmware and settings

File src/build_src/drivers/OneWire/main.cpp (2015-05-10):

/**
 * @file   main.cpp
 * @author Jean-Philippe Fournier
 * @date   Febuary 13 2015
 * @brief  main driver executable for the One wire maxim Ds18b20 device
 * @modified April 10 2015
 * @brief Added error management, to deal with 85 degrees C
 */
 
 //Temporary ID for easy recall of the value, DEV only
#define DEVICE "28-000006052315"

#include "../../commun.h"
#include "OneWireDevice.h"
#include <string>
#include <iostream>

//TO BE VERIFIED 
#include <unistd.h>
#include <stdint.h>
#include <stdio.h>
#include <stdlib.h>

//TO BE REMOVED, TEMPORARY Until name given by command line arguments
#define NOM_TEMPORAIRE "ds18b_0001"

using namespace std;

/**
 * @brief Output the missing arguments phrase for help
 * @return A string that explains the minimum args for the driver to work
 */
string OW_output_missingArguments();

int main(int argc, char * argv[])
{ 
    //floating points to contain read temperature
    float temp;
	//Check for missing arguments, if missing, skip execution and let caller know
    if(argc < OW_MIN_ARGS)
    {
        cout << OW_output_missingArguments() << endl;
        return 1;
    }
	
	//Extract device location from arguments
    string deviceID;
    deviceID.assign(argv[OW_ARG_LOCATION_POS]);
    
	//Create the One Wire device object
    aquarius::OneWireDevice ow(deviceID);
    
    //Path validation...
    if(ow.isValidPath())
    {
        //Device path is valid
        if(ow.updateTemperature())
        {
            //Temperature updated
            if(ow.getLastTemperature(&temp))
            {
                //If temp == 85 there is an error
                if(temp == 85.0f)
                {
                    aquarius::outputError(NOM_TEMPORAIRE, OW_DEVICE_NOT_READY);
                    return 1;
                }
                else
                {
                    //Create an output stream with read data
                    string datas[OW_DATA_QTY] = { to_string(temp) };
                    aquarius::outputReadData(NOM_TEMPORAIRE, OW_DATA_QTY, ow.dataName, datas);
                    return 0;
                }
				
            }
            else
                aquarius::outputError(NOM_TEMPORAIRE, "OW_ERROR_NO_DATA");
        }
        else
            aquarius::outputError(NOM_TEMPORAIRE, "OW_ERROR_NO_RESPONSE");
    }
    else  
        aquarius::outputError(NOM_TEMPORAIRE, "OW_ERROR_NO_DEVICE");
        
    return 1;
}

string OW_output_missingArguments()
{
	return "Missing arguments, could not execute \n\r [Executable] [DeviceLocation] ex: ./driverName 28-000006052315";
}

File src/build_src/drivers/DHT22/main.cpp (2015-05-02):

/**
 * @file   main.cpp
 * @author Jean-Philippe Fournier
 * @date   Febuary 13 2015
 * @brief  Main driver executable file. Driver that asks for input on the location of the DHT22 device on the GPIOs
 */
#include "../../commun.h"
#include "dht22Device.h"
#include <string>
#include <iostream>

//Temporary naming of the device, until the device is given by command line arguments
//TO BE REMOVED
#define NOM_TEMPORAIRE "dht22_0001"

using namespace std;
/**
 * @brief Output the missing arguments phrase for help
 * @return A string that explains the minimum args for the driver to work
 */
string DHT_output_missingArguments();

int main(int argc, char ** argv)
{
	//floating points to contain read temperature an humidity
    float humidity = 0;
    float temperature = 0;
    
	//Check for missing arguments, if missing, skip execution and let caller know
    if(argc < DHT_MIN_ARGS)
    {
        cout << DHT_output_missingArguments() << endl;
        return 1;
    }
    
	//String to contain de the device location arguments
    string deviceLocation;
    deviceLocation.assign(argv[DHT_ARG_LOCATION_POS]);
    
	//Split the arguments with : as delimiter
    vector<string> v{aquarius::splitArguments(deviceLocation, ':')};
    
	//Get both parameters to build DHT device object
    int high = atoi((v[0].c_str())), 
		low = atoi((v[1].c_str()));
    
	//Build DHT device object with both parameters
    aquarius::DHT dht(high, low);
    
	//Init a return value for the reading function    
    int retour = dht.updateData();
    
	//If returned data was good, and the device responded with data
    if(dht.getLatestTemperature(&temperature) && dht.getLatestHumidity(&humidity) && retour >= 0)
    {
		//Create an output stream with both read datas
        string datas[DHT_DATA_QTY] = { to_string(temperature), to_string(humidity) };
        aquarius::outputReadData(NOM_TEMPORAIRE, DHT_DATA_QTY, dht.dataName, datas);
        return 0;
    }
	//If returned data was a timeout error
    else if(retour == DHT_ERROR_TIMEOUT)
    {
        aquarius::outputError(NOM_TEMPORAIRE, "DHT_ERROR_TIMEOUT");
    } 
	//If returned data was a checksum error
    else if(retour == DHT_ERROR_CHECKSUM)
    {
        aquarius::outputError(NOM_TEMPORAIRE, "DHT_ERROR_CHECKSUM");
    }
	//In other cases that are not good
    else
    {
        aquarius::outputError(NOM_TEMPORAIRE, "DHT_UNKNOWN_ERROR");
    }    
    return 1;
}

string DHT_output_missingArguments()
{
	return "Missing arguments, could not execute \n\r [Executable] [DeviceLocation] ex: ./driverName 1:14";
}

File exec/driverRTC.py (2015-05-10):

# RTC DS3231 Driver
# Is used when the Station shutsdown to conserve energy
# @author Jean-Philippe Fournier

import sys, getopt
from Adafruit_I2C import Adafruit_I2C
from subprocess import check_output
from subprocess import call

i2c = Adafruit_I2C(0x68)

######################################################
# function that permits to get a bit in a byte at a position
######################################################
def getBit (byte, position):
    
    bit = (byte >> position) & 1
    
    return bit

######################################################
# function that permits to set a bit in a byte at a position
######################################################
def setBit(byte, position, bit):

    print "Byte before : " + str(byte)

    if bit > 0:
        byte = byte | (1 << position)
    else: 
        dat = ~(1 << position)
        byte = byte & (dat)

    print "Byte after : " + str(byte)

    return byte
######################################################
# function that sets the alarm at the 
######################################################
def setAlarm( hours, minutes ):
    
    print "Hour is : " + str(hours) + " and minutes : " + str(minutes)
    
    i2c.readU8(0x0E)
    
    #Set Seconds bit
    i2c.write8(0x07, setBit(i2c.readU8(0x07), 0, 7))
    
    #Set minutes bit
    i2c.write8(0x08, setBit(i2c.readU8(0x08), 0, 7))
    
    #Set hours bit
    i2c.write8(0x09, setBit(i2c.readU8(0x09), 7, ))
    
    #Set Day
    i2c.write8(0x0A, setBit(i2c.readU8(0x0A), 7, 1))
    
    return 
######################################################
#function that enables the alarm bit on the RTC
######################################################
def enableAlarm():
    resetFlag()
    #Set alarm enable bit
    i2c.write8(0x0E, setBit(i2c.readU8(0x0E), 0, 1))
    
    return 
######################################################
#function that enables the alarm bit on the RTC
######################################################
def disableAlarm():
    resetFlag()
    #Set alarm enable bit
    i2c.write8(0x0E, setBit(i2c.readU8(0x0E), 0, 0))
    
    return 
######################################################
#function that resets the alarm flag
######################################################
def resetFlag():
    
    #Reset alarm flag
    i2c.write8(0x0F, setBit(i2c.readU8(0x0F), 0, 0))
    
    return
######################################################
#Set date from BBB to RTC
######################################################
def setDateFromBBB():

    #With system call to create an RTC device, set and write the date to 
    #the RTC device using system date

    f = open('/sys/class/i2c-adapter/i2c-1/new_device', 'a')
    f.write("ds3231 0x68")
    f.close()
    
    call(["hwclock", "-w", "-f", "/dev/rtc1"])
    
    f = open('/sys/class/i2c-adapter/i2c-1/delete_device', 'a')
    f.write("0x68")
    f.close() 
    return 
######################################################
#Set date from RTC to BBB
######################################################
def setDateFromRTC():

    #With system call to create an RTC device, set and write the date to system
    #with the date in the RTC

    f = open('/sys/class/i2c-adapter/i2c-1/new_device', 'a')
    f.write("ds3231 0x68")
    f.close()
    
    call(["hwclock", "-s", "-f", "/dev/rtc1"])
    call(["hwclock", "-w"])
    
    f = open('/sys/class/i2c-adapter/i2c-1/delete_device', 'a')
    f.write("0x68")
    f.close()
    return 
######################################################
#Function to set alarm minutes
######################################################
def setAlarmMinutes( minutes ):
    m = int(minutes)
    #Sets all Alarm1 bits to enable the minutes and second matching
    #operation mode. Also set the minutes to use as a wake up time
    i2c.write8(0x07, setBit(i2c.readU8(0x07), 7, 0))
    i2c.write8(0x08, setBit(((m / 10) << 4) | ((m % 10)), 7, 0))
    i2c.write8(0x09,setBit(i2c.readU8(0x09), 7, 1))
    i2c.write8(0x0A,setBit(i2c.readU8(0x0A), 7, 1))
    return
######################################################
#Function to set alarm hour
######################################################
def setAlarmHour( hour ):
    h = int(hour)
    #Sets all Alarm1 bits to enable the hour, minutes and second matching
    #operation mode. Also set the hour to use as a wake up time
    i2c.write8(0x07, setBit(i2c.readU8(0x07), 7, 0))
    i2c.write8(0x08, setBit(i2c.readU8(0x08), 7, 0))
    i2c.write8(0x09,setBit(((h / 10) << 4) | ((h % 10)), 7, 1))
    i2c.write8(0x0A,setBit(i2c.readU8(0x0A), 7, 1))
    return
######################################################
#Function to get alarm
######################################################
def getTimeFrom( register ):
    
    if register == "time":
        var = i2c.readList(0x00, 7)
        print "Current time : " + str(getDayFromRegister( var[4] )) + "/" +str( getMonthFromRegister( var[5] )) + "/" + str(getYearFromRegister( var[6] )) + " " + str(getHoursFromRegister( var[2] )) + ":" +str( getMinutesFromRegister( var[1] )) + ":" +str( getSecondsFromRegister( var[0] ))
    elif register == "alarm1":
        var = i2c.readList(0x07, 4)
        print "Current alarm : " + str(getHoursFromRegister(var[2])) + ":" + str(getMinutesFromRegister(var[1])) + ":" + str(getSecondsFromRegister(var[0]))
    else:
        print "Invalid arguments"
    return
######################################################
#Function to get seconds from read register
######################################################
def getSecondsFromRegister( byte ):
    return ((byte >> 4) * 10) + (byte & 0x0F)
######################################################
#Function to get minutes from read register
######################################################
def getMinutesFromRegister( byte ):
    return (((byte >> 4) & 0x7)* 10) + (byte & 0x0F)
######################################################
#function to get hours from read register
######################################################
def getHoursFromRegister( byte ):
    return (((byte >> 4) & 0x01) * 10) + (byte & 0x0F)
######################################################
#function to get day from read register
######################################################
def getDayFromRegister( byte ):
    return (((byte >> 4) & 0x03) * 10) + (byte & 0x0F)
######################################################
#function to get day from read register
######################################################
def getYearFromRegister( byte ):
    return ((byte >> 4) * 10) + (byte & 0x0F)
######################################################
#function to get day from read register
######################################################
def getMonthFromRegister( byte ):
    return (((byte >> 4) & 0x01) * 10) + (byte & 0x0F)
######################################################
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

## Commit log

2015-01-19 Correction et modification de certaines phrases
2015-01-19 Added brd folder to contain the pcb files
    [BeagleCap.brd, BeagleCap.sch, ph-layout.dxf]
2015-01-19 Added folder src/build_src to contain main project source code, mainly drivers but also the main service
2015-01-19 Added src/test_src to contain all unit tests that were produced during the project
    [JSON_Test_JSONCPP.sdf]
2015-01-21 Modification du code de communication I2C
    Permets de tester la communication et d'envoyer des commandes en
    utilisant la ligne de commande
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2015-01-22 Updated I2C test Makefile to follow modifications
    Follows the new library locations to blacklib
2015-01-23 Schematic updated with new PCB
    Done by JayMcGee
    [BeagleCap.brd, BeagleCap2.brd, BeagleCap2.sch]
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2015-01-24 Pcb updated, Fixed DRU error
    [BeagleCap2.brd, BeagleCap2.sch]
2015-01-26 Added a switch to select mode of operation
    [BeagleCap2.brd, BeagleCap2.sch]
2015-02-04 Ajout du projet hexapode de l'an passé pour librairies
    [DRILEGEND.CFG, Project.brd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]
2015-02-04 Updated schematic
    Added:
    RTC
    Logic for power management
    [BeagleCap2.brd, BeagleCap2.sch]
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2015-02-09 Modified Website, fixed error where charts would updates on empty data values, In app.js replace de data of the sensor for a random number generator for test purpose
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2015-02-13 Update Web interface : -Animated Jquery Knobs, -Changed de circleStats positions, text size and footers
2015-02-13 Modification au makefile du DHT22 et autre modifs
    Sur le board
    [BeagleCap2.brd, BeagleCap2.sch]
2015-02-13 Premier brouillons des pilotes pour deux capteurs
    Température et humidité interne ainsi que le capteur de température
    externe
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2015-02-14 Created new folder to avoid overwrite of brd modifications
    [BeagleCap.brd, BeagleCap.sch, BeagleCap2.brd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]
2015-02-14 Minor corrections and comments
    DHT22 update to latest comments and small corrections
    [main.cpp]
2015-02-14 Continued work on PH driver
    Added zone for all command except transfer to serial mode. Added a lot
    of defines to aid in coding. Simplified the command identification,
    refactored some variables to some more expletive names
2015-02-16 PCB update
    Replace some resistor on pcb where they would conflict with the dht22
    [Aquarius.brd, Aquarius.sch, BeagleCap.sch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]
2015-02-16 PCB update
    Changed connectors for battery input
    [Aquarius.brd]
2015-02-18 Added atlas scientific stamp I2C error management
2015-02-18 PCB Update and modified name of Atlas driver cpp's
    [Aquarius.brd, Aquarius.sch, DRILEGEND.CFG]
2015-02-19 PCB JayMcGee Version
    [Aquarius.brd]
2015-02-19 Ajout de ground sur le schema
    Préparation a une 2eime version du PCB
    [Aquarius.brd, Aquarius.sch]
2015-02-19 Added a new PCB version to be selected or not
    [Aquarius.brd, Aquarius.sch]
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2015-02-20 New PCB sketch time for selection
    [Aquarius.brd, Aquarius.sch]
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2015-02-20 Mise a jour du PCB version Jay_brd pour finalisation
    [Aquarius.brd, Aquarius.sch]
2015-02-22 Updated Atlas I2C driver to OOP
    Ready to add drivers for DO and K devices
2015-02-23 Finalisation du pcb avant le test 4pcb
    [Aquarius.brd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]
2015-02-23 Final modifications to PCB for production
    [Aquarius.brd, Aquarius.sch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]
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2015-02-26 Synchronisation du code et du board
    [Aquarius.GTS]
2015-02-26 Deleted some old files + modified makefile to add other I2C devices
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2015-02-27 Compilation correction on new commun file
    Added build details to other drivers so that de commun can compile. This
    will need to change to only compile that file once
    I2C DO an K driver corrections and modifications on I2C general driver
    to read adequatly temperature compensation data
    [Atlas_I2C.cpp, Atlas_I2C_DO.cpp, Atlas_I2C_DO.h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]
2015-02-27 Corrected some parts of the I2C drivers
    [Atlas_I2C_DO.cpp, Atlas_I2C_DO.h, Atlas_I2C_K.cpp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]
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2015-02-28 Completed DO driver to output good data
    And modified the string split length verification method to use the
    DATA_QTY constant
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2015-03-01 Started working on database file export, added USR led close down while in auto mode
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2015-03-13 Ajout du board V2
    [Aquarius.brd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]
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2015-03-18 Added new GPIO driver for each switch
    RTC driver finished, GPIOs also finished, in python
2015-03-18 Deleted some deprecated folders
    [BeagleCap.brd, BeagleCap.sch, BeagleCap2.brd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]
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2015-03-18 Second draft of sync read + async insert into final database. app.js now retrieves installed sensor list from database
2015-03-20 Adds functional configuration page to project, can now configure some parameters from /form.html Service also keeps track of last know date
2015-03-21 Added more messages in install.sh process Comments and optimization in app.js Created a configuration var for current operative mode
2015-03-23 Added logic to ensure finish reading sensors before rebooting in auto mode -JP
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2015-03-27 Added CONFIG reading operation to SensorHelper module, added DEGUB verbose levels to database
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2015-04-08 Added error management to OneWire driver. Changed logic of DEL python driver to match desired functionality
    [commun.h, driverRTC.py, main.cpp]
2015-04-10 Added new temperature compensation to reading operations on I2C devices Added new GPS functions for SIM908
2015-04-10 Corrected bug that stopped reading sensors. Was caused by DEL functions take to much CPU time. Put as async exec
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2015-04-12 Added 1W DTS file and minor additions to SIM908 driver
    Install SH to be completed with added compilation of DTS of 1W driver.
2015-04-13 Fixed retry test in app.js on sensor reading
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2015-04-18 Added new .patch if the file la solution does not contain a solution to the non reboot problematic
2015-04-18 Small error on command line to close all power
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2015-04-27 Corrected drivers to ouput based on string, added removing of non numeric caracters in value returned for update of sensor
    [Atlas_I2C_DO.cpp, Atlas_I2C_DO.h, Atlas_I2C_K.cpp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]
2015-04-27 Minor corrections to GPS driver in preparation to integration
    [Atlas_I2C_K.cpp, driverSIM908.py]
2015-04-29 Corrected calibration on the DO stamp
    [Atlas_I2C_DO.cpp, driverAtlas_I2CDO.cpp]
2015-04-29 Corrected errors in calibration of K stamp, does a dry calibration with a clear
    [Atlas_I2C_K.cpp, driverRTC.py]
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2015-05-05 Cleanup of some includes, changed fona and gprs copy into make of sim908 driver Changed install.sh orders and added make Moved install of 1W driver dts into make
2015-05-06 Corrected driver Atlas to use a argument passed temperature compensation
    [driverAtlas_I2CDO.cpp, driverAtlas_I2CK.cpp, driverAtlas_I2CPH.cpp]
2015-05-06 Driver sim908 updated with cold reset
    [driverSIM908.py]
2015-05-08 Minor corrections for milestone 1
    [driverRTC.py, driverSIM908.py]
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2015-05-08 Corrected OneWire driver to look for presence of driver in w1_slave file
    [Atlas_I2C.h, driverSIM908.py, main.cpp]
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2015-05-09 Finished comment on switches, adc and LED gpio files Renamed LED gpio files to better explain their use Changed names for LED files in app.js
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2015-05-10 Renamed aquariusSensorHelper to more friendly and descriptive name Commented code in app.js and refactored function and var names Added new file to be used as script to disable USR LED in auto mode
2015-05-10 Deleted unecessary files
    [Aquarius.brd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]
2015-05-11 Corrected app js operations
    [Atlas_I2C_PH.cpp]
2015-05-11 Corrected calibration logic in index.html to send value
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2015-05-14 Deleted unecessary files part deux
    All unused files and deleted compiled files
    [JSON_Test_JSONCPP.sdf]
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2015-05-28 Added check for the gps fix. If there is a not a fix, call an error
    [driverSIM908.py]
2015-05-29 UI tweaks made by JayMcGee. Merge needed
    [export.csv]
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2015-05-29 Added sensor measure error management
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2015-05-29 Corrected an error in the sim908 driver, one equal to much
    [driverSIM908.py]
2015-05-29 Missing two double points after condition checking
    [driverSIM908.py]
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2015-06-01 Corrected errors in data trasmission with sim908. Shows debug informatiom
    [driverSIM908.py]
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2015-06-02 Corrected errors on ds18b20 device detection
2015-06-02 Added functions to stop LED on the pcb during execution of auto mode
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2015-06-08 Added Results of the test in Brasil, Amarelo
    [Test_au_Bresil_Amarelo.csv]
2015-06-08 Added Charts to Results
    [Test_au_Bresil_Amarelo.csv]
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

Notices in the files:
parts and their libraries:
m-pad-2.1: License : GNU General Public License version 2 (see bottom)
